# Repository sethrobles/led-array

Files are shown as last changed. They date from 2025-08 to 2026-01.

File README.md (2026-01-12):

# LED Array (32×32 STM32-Driven Matrix)

This repository contains the **hardware design and firmware** for a custom **32×32 LED matrix PCB** designed in **KiCad** and driven by an **STM32 microcontroller**.

The project was built both as a learning exercise in multi-layer PCB design and as a functional, firmware-controlled LED display.

🔗 **Project blog / design log:**
https://sethrobles.github.io/blogs/led-array/

---

## Project Overview

The LED array is implemented as a multiplexed matrix driven by shift registers and MOSFETs, with all timing and animation handled in firmware.

### Hardware Features

- **32×32 LED matrix** (1,032 LEDs total)
- **16× 74HC595 shift registers** for serial-to-parallel expansion
- **8× N-channel MOSFETs** for row/column current switching
- **STM32 microcontroller** for scanning, timing, and animation logic
- **On-board buck converter** for efficient 3.3 V regulation
- **4-layer PCB** designed and routed in KiCad
- **Hierarchical schematics** to support scalable layout and reuse

## Schematic Structure

The board uses an **on-board switching buck converter (TPS54331DR)** to step a ~5 V input down to 3.3V for the STM32 and logic circuitry.

The design uses a hierarchical schematic organization to keep both the schematic and PCB layout manageable:

- **LED Row**: 8 LEDs tied to a single shift-register output
- **LED Module**: One shift register driving 64 LEDs
- **LED Group**: Four LED modules grouped for layout and logic convenience

In total:
- **16 shift registers**
- **1,032 LEDs**

---

## Firmware

Firmware is written using **STM32CubeIDE** and is responsible for:

- High-speed LED scanning
- Register shifting and latch control
- Multiplex timing
- Multiple animation modes (spirals, perimeter effects, hearts, text, etc.)
- Minimizing ghosting and partial illumination

Programming and debugging are currently done using **ST-Link**. A future revision may include a USB bootloader to eliminate the need for programming headers.

Firmware lives alongside the hardware files but is kept logically separate. It is divided into 3 .c files: main, led_array, and frames. Main is actually uploaded to the board, led_array includes the basic logic for programming a frame, and frames contains specific frames for the board that build the animations.

---

## Repository Structure

- `Firmware/` – STM32 firmware source (CubeIDE project)
- KiCad project files – schematics, PCB layout, and libraries
- Backup and fabrication-related artifacts (not required for normal use)

---

## Status

The board has been fabricated, assembled, powered, and tested:

- Buck converter output verified (~20 mV ripple observed)
- STM32 successfully flashed and running on hardware
- LED scanning and animations functional

---

## Motivation & Inspiration

This project was inspired by:
- Phil’s Lab STM32 PCB design tutorials
- Guidance and feedback from friends with PCB design experience

The full design process, decisions, mistakes, and lessons learned are documented on the project blog.

📖 **Read the full build log:**
https://sethrobles.github.io/blogs/led-array/

*Summary Written with ChatGPT

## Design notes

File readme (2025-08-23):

# KiCad LED Array 🚧 (Work in Progress)

This project is a custom PCB built in **KiCad** that drives a 32×32 LED matrix using an **STM32 microcontroller**.

The design features:
- **8 NFETs** for row/column control
- **16 shift registers (74HC595)** for serial-to-parallel expansion
- A hierarchical schematic setup for scalability

### Inspiration
This project was inspired (and guided) by my friend [@floreacton](https://github.com/floreacton).

---

## Current Status
🚧 **In Progress**
This design is still being prototyped. Expect changes to both the schematic and PCB layout as I refine the design.

---

## Goals
- [ ] Finish schematic design and ERC checks
- [ ] Route PCB with proper 4-layer stackup
- [ ] Order prototype boards from JLCPCB
- [ ] Test LED scanning with STM32 firmware

---

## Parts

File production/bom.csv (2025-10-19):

Designator | Footprint | Quantity | Value | LCSC Part #
C1 | 1206 | 1 | 22uF | C12891
C10, C12, C13, C17, C18, C19, C20, C21, C22, C23, C24, C25, C26, C27, C28, C29, C3, C30, C31, C32, C7, C9 | 0402 | 22 | 100nF | C1525
C11, C33, C8 | 0402 | 3 | 10pF | C32949
C14 | 0603 | 1 | 10nF | C57112
C15, C16 | 0603 | 2 | 1uF | C15849
C2 | 0603 | 1 | 8n2F | C1322360
C4 | 0402 | 1 | 1nF | C1523
C5 | 1206 | 1 | 100uF | C15008
C6 | 1206 | 1 | 10uF | C13585
D1 | 0805 | 1 | GREEN_LIGHT | C2297
D10, D100, D1000, D1001, D1002, D1003, D1004, D1005, D1006, D1007, D1008, D1009, D101, D1010, D1011, D1012, D1013, D1014, D1015, D1016, D1017, D1018, D1019, D102, D1020, D1021, D1022, D1023, D1024, D1025, D103, D104, D105, D106, D107, D108, D109, D11, D110, D111, D112, D113, D114, D115, D116, D117, D118, D119, D12, D120, D121, D122, D123, D124, D125, D126, D127, D128, D129, D13, D130, D131, D132, D133, D134, D135, D136, D137, D138, D139, D14, D140, D141, D142, D143, D144, D145, D146, D147, D148, D149, D15, D150, D151, D152, D153, D154, D155, D156, D157, D158, D159, D16, D160, D161, D162, D163, D164, D165, D166, D167, D168, D169, D17, D170, D171, D172, D173, D174, D175, D176, D177, D178, D179, D18, D180, D181, D182, D183, D184, D185, D186, D187, D188, D189, D19, D190, D191, D192, D193, D194, D195, D196, D197, D198, D199, D2, D20, D200, D201, D202, D203, D204, D205, D206, D207, D208, D209, D21, D210, D211, D212, D213, D214, D215, D216, D217, D218, D219, D22, D220, D221, D222, D223, D224, D225, D226, D227, D228, D229, D23, D230, D231, D232, D233, D234, D235, D236, D237, D238, D239, D24, D240, D241, D242, D243, D244, D245, D246, D247, D248, D249, D25, D250, D251, D252, D253, D254, D255, D256 | 0603 | 200 | RED | C2286
D1026 | D_SMA | 1 | D_Schottky | C14996
D257, D258, D259, D26, D260, D261, D262, D263, D264, D265, D266, D267, D268, D269, D27, D270, D271, D272, D273, D274, D275, D276, D277, D278, D279, D28, D280, D281, D282, D283, D284, D285, D286, D287, D288, D289, D29, D290, D291, D292, D293, D294, D295, D296, D297, D298, D299, D3, D30, D300, D301, D302, D303, D304, D305, D306, D307, D308, D309, D31, D310, D311, D312, D313, D314, D315, D316, D317, D318, D319, D32, D320, D321, D322, D323, D324, D325, D326, D327, D328, D329, D33, D330, D331, D332, D333, D334, D335, D336, D337, D338, D339, D34, D340, D341, D342, D343, D344, D345, D346, D347, D348, D349, D35, D350, D351, D352, D353, D354, D355, D356, D357, D358, D359, D36, D360, D361, D362, D363, D364, D365, D366, D367, D368, D369, D37, D370, D371, D372, D373, D374, D375, D376, D377, D378, D379, D38, D380, D381, D382, D383, D384, D385, D386, D387, D388, D389, D39, D390, D391, D392, D393, D394, D395, D396, D397, D398, D399, D4, D40, D400, D401, D402, D403, D404, D405, D406, D407, D408, D409, D41, D410, D411, D412, D413, D414, D415, D416, D417, D418, D419, D42, D420, D421, D422, D423, D424, D425, D426, D427, D428, D429, D43, D430, D431, D432, D433, D434, D435, D436 | 0603 | 200 | RED | C2286
D437, D438, D439, D44, D440, D441, D442, D443, D444, D445, D446, D447, D448, D449, D45, D450, D451, D452, D453, D454, D455, D456, D457, D458, D459, D46, D460, D461, D462, D463, D464, D465, D466, D467, D468, D469, D47, D470, D471, D472, D473, D474, D475, D476, D477, D478, D479, D48, D480, D481, D482, D483, D484, D485, D486, D487, D488, D489, D49, D490, D491, D492, D493, D494, D495, D496, D497, D498, D499, D5, D50, D500, D501, D502, D503, D504, D505, D506, D507, D508, D509, D51, D510, D511, D512, D513, D514, D515, D516, D517, D518, D519, D52, D520, D521, D522, D523, D524, D525, D526, D527, D528, D529, D53, D530, D531, D532, D533, D534, D535, D536, D537, D538, D539, D54, D540, D541, D542, D543, D544, D545, D546, D547, D548, D549, D55, D550, D551, D552, D553, D554, D555, D556, D557, D558, D559, D56, D560, D561, D562, D563, D564, D565, D566, D567, D568, D569, D57, D570, D571, D572, D573, D574, D575, D576, D577, D578, D579, D58, D580, D581, D582, D583, D584, D585, D586, D587, D588, D589, D59, D590, D591, D592, D593, D594, D595, D596, D597, D598, D599, D6, D60, D600, D601, D602, D603, D604, D605, D606, D607, D608, D609, D61, D610, D611, D612, D613, D614, D615, D616 | 0603 | 200 | RED | C2286
D617, D618, D619, D62, D620, D621, D622, D623, D624, D625, D626, D627, D628, D629, D63, D630, D631, D632, D633, D634, D635, D636, D637, D638, D639, D64, D640, D641, D642, D643, D644, D645, D646, D647, D648, D649, D65, D650, D651, D652, D653, D654, D655, D656, D657, D658, D659, D66, D660, D661, D662, D663, D664, D665, D666, D667, D668, D669, D67, D670, D671, D672, D673, D674, D675, D676, D677, D678, D679, D68, D680, D681, D682, D683, D684, D685, D686, D687, D688, D689, D69, D690, D691, D692, D693, D694, D695, D696, D697, D698, D699, D7, D70, D700, D701, D702, D703, D704, D705, D706, D707, D708, D709, D71, D710, D711, D712, D713, D714, D715, D716, D717, D718, D719, D72, D720, D721, D722, D723, D724, D725, D726, D727, D728, D729, D73, D730, D731, D732, D733, D734, D735, D736, D737, D738, D739, D74, D740, D741, D742, D743, D744, D745, D746, D747, D748, D749, D75, D750, D751, D752, D753, D754, D755, D756, D757, D758, D759, D76, D760, D761, D762, D763, D764, D765, D766, D767, D768, D769, D77, D770, D771, D772, D773, D774, D775, D776, D777, D778, D779, D78, D780, D781, D782, D783, D784, D785, D786, D787, D788, D789, D79, D790, D791, D792, D793, D794, D795, D796, D797 | 0603 | 200 | RED | C2286
D798, D799, D8, D80, D800, D801, D802, D803, D804, D805, D806, D807, D808, D809, D81, D810, D811, D812, D813, D814, D815, D816, D817, D818, D819, D82, D820, D821, D822, D823, D824, D825, D826, D827, D828, D829, D83, D830, D831, D832, D833, D834, D835, D836, D837, D838, D839, D84, D840, D841, D842, D843, D844, D845, D846, D847, D848, D849, D85, D850, D851, D852, D853, D854, D855, D856, D857, D858, D859, D86, D860, D861, D862, D863, D864, D865, D866, D867, D868, D869, D87, D870, D871, D872, D873, D874, D875, D876, D877, D878, D879, D88, D880, D881, D882, D883, D884, D885, D886, D887, D888, D889, D89, D890, D891, D892, D893, D894, D895, D896, D897, D898, D899, D9, D90, D900, D901, D902, D903, D904, D905, D906, D907, D908, D909, D91, D910, D911, D912, D913, D914, D915, D916, D917, D918, D919, D92, D920, D921, D922, D923, D924, D925, D926, D927, D928, D929, D93, D930, D931, D932, D933, D934, D935, D936, D937, D938, D939, D94, D940, D941, D942, D943, D944, D945, D946, D947, D948, D949, D95, D950, D951, D952, D953, D954, D955, D956, D957, D958, D959, D96, D960, D961, D962, D963, D964, D965, D966, D967, D968, D969, D97, D970, D971, D972, D973, D974, D975, D976, D977 | 0603 | 200 | RED | C2286
D978, D979, D98, D980, D981, D982, D983, D984, D985, D986, D987, D988, D989, D99, D990, D991, D992, D993, D994, D995, D996, D997, D998, D999 | 0603 | 24 | RED | C2286
FB1 | 0603 | 1 | 120FB | C14709
J1 | PinHeader_1x04_P2.54mm_Vertical | 1 | Conn_01x04_Pin | C5116483
J2 | USB_Micro-B_Molex-105017-0001 | 1 | USB_B_Micro | C136000
L1 | L_Bourns-SRN8040_8x8.15mm | 1 | 3.6uH | C6496151
Q1, Q2, Q3, Q4, Q5, Q6, Q7, Q8 | SOT-23 | 8 | Q_NMOS_GDS | C8545
R1, R4 | 0805 | 2 | 10k | C17414
R10, R100, R101, R102, R103, R104, R105, R106, R107, R108, R109, R11, R110, R111, R112, R113, R114, R115, R116, R117, R118, R119, R12, R120, R121, R122, R123, R124, R125, R126, R127, R128, R129, R13, R130, R131, R132, R133, R134, R14, R15, R16, R17, R18, R19, R20, R21, R22, R23, R24, R25, R26, R27, R28, R29, R30, R31, R32, R33, R34, R35, R36, R37, R38, R39, R40, R41, R42, R43, R44, R45, R46, R47, R48, R49, R50, R51, R52, R53, R54, R55, R56, R57, R58, R59, R60, R61, R62, R63, R64, R65, R66, R67, R68, R69, R7, R70, R71, R72, R73, R74, R75, R76, R77, R78, R79, R8, R80, R81, R82, R83, R84, R85, R86, R87, R88, R89, R9, R90, R91, R92, R93, R94, R95, R96, R97, R98, R99 | 0402 | 128 | 200 | C25087
R135 | 0402 | 1 | 33k | C25779
R136 | 0402 | 1 | 3.3k | C25890
R2 | 0402 | 1 | 2k | C4109
R3 | 0603 | 1 | 1k2 | C22765
R5 | 0402 | 1 | 470 | C25117
R6 | 0603 | 1 | 1k5 | C22843
U1 | SOIC-8_3.9x4.9mm_P1.27mm | 1 | TPS54331DR | C9865
U10, U11, U12, U13, U14, U15, U16, U17, U18, U3, U4, U5, U6, U7, U8, U9 | SOIC-16_3.9x9.9mm_P1.27mm | 16 | 74HC595 | C5947
U2 | LQFP-48_7x7mm_P0.5mm | 1 | STM32F103C8T6 | C8734
Y1 | Crystal_SMD_3225-4Pin_3.2x2.5mm | 1 | 16MHz | C9002

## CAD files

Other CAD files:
qr-code/seth_qr.dxf

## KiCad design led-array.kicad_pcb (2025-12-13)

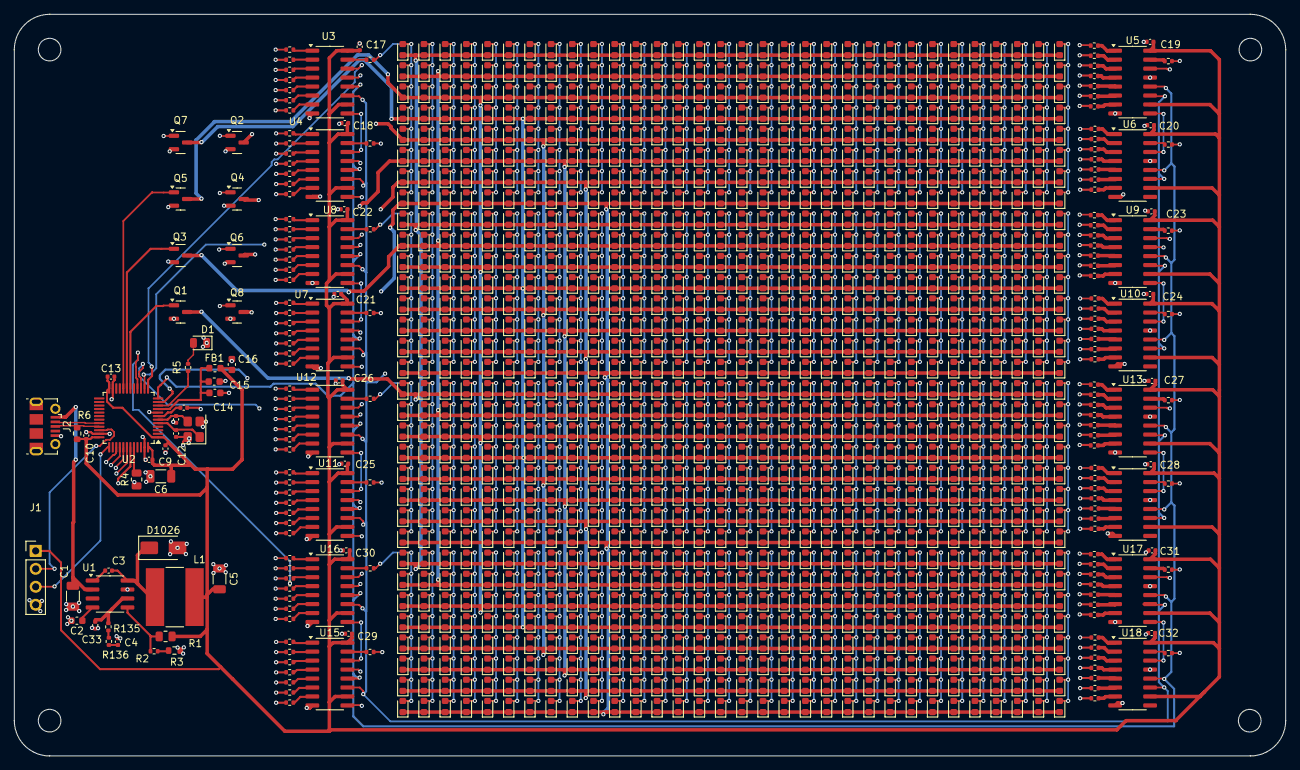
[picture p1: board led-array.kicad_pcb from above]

Board: 4 copper layers, 180.0 x 105.0 mm, 1230 parts (0 on the bottom side), 312 nets.

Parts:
C1: 22uF; C_1206_3216Metric
C2: 8n2F; C_0603_1608Metric
C3, C7, C9, C10, C12, C13, C17, C18, C19, C20, C21, C22, C23, C24, C25, C26, C27, C28, C29, C30, C31, C32: 100nF; C_0402_1005Metric
C4: 1nF; C_0402_1005Metric
C5: 100uF; C_1206_3216Metric
C6: 10uF; C_1206_3216Metric
C8, C11, C33: 10pF; C_0402_1005Metric
C14: 10nF; C_0603_1608Metric
C15, C16: 1uF; C_0603_1608Metric
D1: GREEN_LIGHT; LED_0805_2012Metric
D2, D3, D4, D5, D6, D7, D8, D9, D10, D11, D12, D13, D14, D15, D16, D17, D18, D19, D20, D21, D22, D23, D24, D25, D26, D27, D28, D29, D30, D31, D32, D33, D34, D35, D36, D37, D38, D39, D40, D41, D42, D43, D44, D45, D46, D47, D48, D49, D50, D51, D52, D53, D54, D55, D56, D57, D58, D59, D60, D61, D62, D63, D64, D65, D66, D67, D68, D69, D70, D71, D72, D73, D74, D75, D76, D77, D78, D79, D80, D81, D82, D83, D84, D85, D86, D87, D88, D89, D90, D91, D92, D93, D94, D95, D96, D97, D98, D99, D100, D101, D102, D103, D104, D105, D106, D107, D108, D109, D110, D111, D112, D113, D114, D115, D116, D117, D118, D119, D120, D121, D122, D123, D124, D125, D126, D127, D128, D129, D130, D131, D132, D133, D134, D135, D136, D137, D138, D139, D140, D141, D142, D143, D144, D145, D146, D147, D148, D149, D150, D151, D152, D153, D154, D155, D156, D157, D158, D159, D160, D161, D162, D163, D164, D165, D166, D167, D168, D169, D170, D171, D172, D173, D174, D175, D176, D177, D178, D179, D180, D181, D182, D183, D184, D185, D186, D187, D188, D189, D190, D191, D192, D193, D194, D195, D196, D197, D198, D199, D200, D201, D202, D203, D204, D205, D206, D207, D208, D209, D210, D211, D212, D213, D214, D215, D216, D217, D218, D219, D220, D221, D222, D223, D224, D225, D226, D227, D228, D229, D230, D231, D232, D233, D234, D235, D236, D237, D238, D239, D240, D241, D242, D243, D244, D245, D246, D247, D248, D249, D250, D251, D252, D253, D254, D255, D256, D257, D258, D259, D260, D261, D262, D263, D264, D265, D266, D267, D268, D269, D270, D271, D272, D273, D274, D275, D276, D277, D278, D279, D280, D281, D282, D283, D284, D285, D286, D287, D288, D289, D290, D291, D292, D293, D294, D295, D296, D297, D298, D299, D300, D301, D302, D303, D304, D305, D306, D307, D308, D309, D310, D311, D312, D313, D314, D315, D316, D317, D318, D319, D320, D321, D322, D323, D324, D325, D326, D327, D328, D329, D330, D331, D332, D333, D334, D335, D336, D337, D338, D339, D340, D341, D342, D343, D344, D345, D346, D347, D348, D349, D350, D351, D352, D353, D354, D355, D356, D357, D358, D359, D360, D361, D362, D363, D364, D365, D366, D367, D368, D369, D370, D371, D372, D373, D374, D375, D376, D377, D378, D379, D380, D381, D382, D383, D384, D385, D386, D387, D388, D389, D390, D391, D392, D393, D394, D395, D396, D397, D398, D399, D400, D401, D402, D403, D404, D405, D406, D407, D408, D409, D410, D411, D412, D413, D414, D415, D416, D417, D418, D419, D420, D421, D422, D423, D424, D425, D426, D427, D428, D429, D430, D431, D432, D433, D434, D435, D436, D437, D438, D439, D440, D441, D442, D443, D444, D445, D446, D447, D448, D449, D450, D451, D452, D453, D454, D455, D456, D457, D458, D459, D460, D461, D462, D463, D464, D465, D466, D467, D468, D469, D470, D471, D472, D473, D474, D475, D476, D477, D478, D479, D480, D481, D482, D483, D484, D485, D486, D487, D488, D489, D490, D491, D492, D493, D494, D495, D496, D497, D498, D499, D500, D501, D502, D503, D504, D505, D506, D507, D508, D509, D510, D511, D512, D513, D514, D515, D516, D517, D518, D519, D520, D521, D522, D523, D524, D525, D526, D527, D528, D529, D530, D531, D532, D533, D534, D535, D536, D537, D538, D539, D540, D541, D542, D543, D544, D545, D546, D547, D548, D549, D550, D551, D552, D553, D554, D555, D556, D557, D558, D559, D560, D561, D562, D563, D564, D565, D566, D567, D568, D569, D570, D571, D572, D573, D574, D575, D576, D577, D578, D579, D580, D581, D582, D583, D584, D585, D586, D587, D588, D589, D590, D591, D592, D593, D594, D595, D596, D597, D598, D599, D600, D601, D602, D603, D604, D605, D606, D607, D608, D609, D610, D611, D612, D613, D614, D615, D616, D617, D618, D619, D620, D621, D622, D623, D624, D625, D626, D627, D628, D629, D630, D631, D632, D633, D634, D635, D636, D637, D638, D639, D640, D641, D642, D643, D644, D645, D646, D647, D648, D649, D650, D651, D652, D653, D654, D655, D656, D657, D658, D659, D660, D661, D662, D663, D664, D665, D666, D667, D668, D669, D670, D671, D672, D673, D674, D675, D676, D677, D678, D679, D680, D681, D682, D683, D684, D685, D686, D687, D688, D689, D690, D691, D692, D693, D694, D695, D696, D697, D698, D699, D700, D701, D702, D703, D704, D705, D706, D707, D708, D709, D710, D711, D712, D713, D714, D715, D716, D717, D718, D719, D720, D721, D722, D723, D724, D725, D726, D727, D728, D729, D730, D731, D732, D733, D734, D735, D736, D737, D738, D739, D740, D741, D742, D743, D744, D745, D746, D747, D748, D749, D750, D751, D752, D753, D754, D755, D756, D757, D758, D759, D760, D761, D762, D763, D764, D765, D766, D767, D768, D769, D770, D771, D772, D773, D774, D775, D776, D777, D778, D779, D780, D781, D782, D783, D784, D785, D786, D787, D788, D789, D790, D791, D792, D793, D794, D795, D796, D797, D798, D799, D800, D801, D802, D803, D804, D805, D806, D807, D808, D809, D810, D811, D812, D813, D814, D815, D816, D817, D818, D819, D820, D821, D822, D823, D824, D825, D826, D827, D828, D829, D830, D831, D832, D833, D834, D835, D836, D837, D838, D839, D840, D841, D842, D843, D844, D845, D846, D847, D848, D849, D850, D851, D852, D853, D854, D855, D856, D857, D858, D859, D860, D861, D862, D863, D864, D865, D866, D867, D868, D869, D870, D871, D872, D873, D874, D875, D876, D877, D878, D879, D880, D881, D882, D883, D884, D885, D886, D887, D888, D889, D890, D891, D892, D893, D894, D895, D896, D897, D898, D899, D900, D901, D902, D903, D904, D905, D906, D907, D908, D909, D910, D911, D912, D913, D914, D915, D916, D917, D918, D919, D920, D921, D922, D923, D924, D925, D926, D927, D928, D929, D930, D931, D932, D933, D934, D935, D936, D937, D938, D939, D940, D941, D942, D943, D944, D945, D946, D947, D948, D949, D950, D951, D952, D953, D954, D955, D956, D957, D958, D959, D960, D961, D962, D963, D964, D965, D966, D967, D968, D969, D970, D971, D972, D973, D974, D975, D976, D977, D978, D979, D980, D981, D982, D983, D984, D985, D986, D987, D988, D989, D990, D991, D992, D993, D994, D995, D996, D997, D998, D999, D1000, D1001, D1002, D1003, D1004, D1005, D1006, D1007, D1008, D1009, D1010, D1011, D1012, D1013, D1014, D1015, D1016, D1017, D1018, D1019, D1020, D1021, D1022, D1023, D1024, D1025: RED; LED_0603_1608Metric
D1026: D_Schottky; D_SMA
FB1: 120FB; L_0603_1608Metric
H1, H2, H3, H4: MountingHole; MountingHole_3.2mm_M3
J1: Conn_01x04_Pin; PinHeader_1x04_P2.54mm_Vertical
J2: USB_B_Micro; USB_Micro-B_Molex-105017-0001
L1: 3.6uH; L_Bourns-SRN8040_8x8.15mm
Q1, Q2, Q3, Q4, Q5, Q6, Q7, Q8: Q_NMOS_GDS; SOT-23
R1, R4: 10k; R_0805_2012Metric
R2: 2k; R_0402_1005Metric
R3: 1k2; R_0603_1608Metric
R5: 470; R_0402_1005Metric
R6: 1k5; R_0603_1608Metric
R7, R8, R9, R10, R11, R12, R13, R14, R15, R16, R17, R18, R19, R20, R21, R22, R23, R24, R25, R26, R27, R28, R29, R30, R31, R32, R33, R34, R35, R36, R37, R38, R39, R40, R41, R42, R43, R44, R45, R46, R47, R48, R49, R50, R51, R52, R53, R54, R55, R56, R57, R58, R59, R60, R61, R62, R63, R64, R65, R66, R67, R68, R69, R70, R71, R72, R73, R74, R75, R76, R77, R78, R79, R80, R81, R82, R83, R84, R85, R86, R87, R88, R89, R90, R91, R92, R93, R94, R95, R96, R97, R98, R99, R100, R101, R102, R103, R104, R105, R106, R107, R108, R109, R110, R111, R112, R113, R114, R115, R116, R117, R118, R119, R120, R121, R122, R123, R124, R125, R126, R127, R128, R129, R130, R131, R132, R133, R134: 200; R_0402_1005Metric
R135: 33k; R_0402_1005Metric
R136: 3.3k; R_0402_1005Metric
U1: TPS54331DR; SOIC-8_3.9x4.9mm_P1.27mm
U2: STM32F103C8T6; LQFP-48_7x7mm_P0.5mm
U3, U4, U5, U6, U7, U8, U9, U10, U11, U12, U13, U14, U15, U16, U17, U18: 74HC595; SOIC-16_3.9x9.9mm_P1.27mm
Y1: 16MHz; Crystal_SMD_3225-4Pin_3.2x2.5mm

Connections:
+3.3V: C5.1, C6.1, C9.1, C10.1, C12.1, C13.1, C16.1, C17.1, C18.1, C19.1, C20.1, C21.1, C22.1, C23.1, C24.1, C25.1, C26.1, C27.1, C28.1, C29.1, C30.1, C31.1, C32.1, FB1.2, J1.1, L1.2, R1.1, R6.2, U2.1 (VBAT), U2.24 (VDD), U2.36 (VDD), U2.48 (VDD), U3.10 (~SRCLR), U3.16 (VCC), U4.10 (~SRCLR), U4.16 (VCC), U5.10 (~SRCLR), U5.16 (VCC), U6.10 (~SRCLR), U6.16 (VCC), U7.10 (~SRCLR), U7.16 (VCC), U8.10 (~SRCLR), U8.16 (VCC), U9.10 (~SRCLR), U9.16 (VCC), U10.10 (~SRCLR), U10.16 (VCC), U11.10 (~SRCLR), U11.16 (VCC), U12.10 (~SRCLR), U12.16 (VCC), U13.10 (~SRCLR), U13.16 (VCC), U14.10 (~SRCLR), U14.16 (VCC), U15.10 (~SRCLR), U15.16 (VCC), U16.10 (~SRCLR), U16.16 (VCC), U17.10 (~SRCLR), U17.16 (VCC), U18.10 (~SRCLR), U18.16 (VCC)
+3.3VA: C14.1, C15.1, FB1.1, U2.9 (VDDA)
/BOOT0: R4.2, U2.44 (BOOT0)
/Cboot: C3.2, U1.1 (BOOT)
/HSE_IN: C8.2, U2.5 (PD0), Y1.1
/HSE_OUT: C11.2, U2.6 (PD1), Y1.3
/LED Group 0/Led Module 1/A0: D2.2 (A), D10.2 (A), D18.2 (A), D26.2 (A), D34.2 (A), D42.2 (A), D50.2 (A), D58.2 (A), R7.2
/LED Group 0/Led Module 1/A1: D3.2 (A), D11.2 (A), D19.2 (A), D27.2 (A), D35.2 (A), D43.2 (A), D51.2 (A), D59.2 (A), R8.2
/LED Group 0/Led Module 1/A2: D4.2 (A), D12.2 (A), D20.2 (A), D28.2 (A), D36.2 (A), D44.2 (A), D52.2 (A), D60.2 (A), R9.2
/LED Group 0/Led Module 1/A3: D5.2 (A), D13.2 (A), D21.2 (A), D29.2 (A), D37.2 (A), D45.2 (A), D53.2 (A), D61.2 (A), R10.2
/LED Group 0/Led Module 1/A4: D6.2 (A), D14.2 (A), D22.2 (A), D30.2 (A), D38.2 (A), D46.2 (A), D54.2 (A), D62.2 (A), R11.2
/LED Group 0/Led Module 1/A5: D7.2 (A), D15.2 (A), D23.2 (A), D31.2 (A), D39.2 (A), D47.2 (A), D55.2 (A), D63.2 (A), R12.2
/LED Group 0/Led Module 1/A6: D8.2 (A), D16.2 (A), D24.2 (A), D32.2 (A), D40.2 (A), D48.2 (A), D56.2 (A), D64.2 (A), R13.2
/LED Group 0/Led Module 1/A7: D9.2 (A), D17.2 (A), D25.2 (A), D33.2 (A), D41.2 (A), D49.2 (A), D57.2 (A), D65.2 (A), R14.2
/LED Group 0/Led Module 1/OUT: U3.9 (QH'), U4.14 (SER)
/LED Group 0/Led Module 2/A0: D66.2 (A), D74.2 (A), D82.2 (A), D90.2 (A), D98.2 (A), D106.2 (A), D114.2 (A), D122.2 (A), R15.2
/LED Group 0/Led Module 2/A1: D67.2 (A), D75.2 (A), D83.2 (A), D91.2 (A), D99.2 (A), D107.2 (A), D115.2 (A), D123.2 (A), R16.2
/LED Group 0/Led Module 2/A2: D68.2 (A), D76.2 (A), D84.2 (A), D92.2 (A), D100.2 (A), D108.2 (A), D116.2 (A), D124.2 (A), R17.2
/LED Group 0/Led Module 2/A3: D69.2 (A), D77.2 (A), D85.2 (A), D93.2 (A), D101.2 (A), D109.2 (A), D117.2 (A), D125.2 (A), R18.2
/LED Group 0/Led Module 2/A4: D70.2 (A), D78.2 (A), D86.2 (A), D94.2 (A), D102.2 (A), D110.2 (A), D118.2 (A), D126.2 (A), R19.2
/LED Group 0/Led Module 2/A5: D71.2 (A), D79.2 (A), D87.2 (A), D95.2 (A), D103.2 (A), D111.2 (A), D119.2 (A), D127.2 (A), R20.2
/LED Group 0/Led Module 2/A6: D72.2 (A), D80.2 (A), D88.2 (A), D96.2 (A), D104.2 (A), D112.2 (A), D120.2 (A), D128.2 (A), R21.2
/LED Group 0/Led Module 2/A7: D73.2 (A), D81.2 (A), D89.2 (A), D97.2 (A), D105.2 (A), D113.2 (A), D121.2 (A), D129.2 (A), R22.2
/LED Group 0/Led Module 2/OUT: U4.9 (QH'), U5.14 (SER)
/LED Group 0/Led Module 3/A0: D130.2 (A), D138.2 (A), D146.2 (A), D154.2 (A), D162.2 (A), D170.2 (A), D218.2 (A), D226.2 (A), R23.2
/LED Group 0/Led Module 3/A1: D131.2 (A), D139.2 (A), D147.2 (A), D155.2 (A), D163.2 (A), D171.2 (A), D219.2 (A), D227.2 (A), R24.2
/LED Group 0/Led Module 3/A2: D132.2 (A), D140.2 (A), D148.2 (A), D156.2 (A), D164.2 (A), D172.2 (A), D220.2 (A), D228.2 (A), R25.2
/LED Group 0/Led Module 3/A3: D133.2 (A), D141.2 (A), D149.2 (A), D157.2 (A), D165.2 (A), D173.2 (A), D221.2 (A), D229.2 (A), R26.2
/LED Group 0/Led Module 3/A4: D134.2 (A), D142.2 (A), D150.2 (A), D158.2 (A), D166.2 (A), D174.2 (A), D222.2 (A), D230.2 (A), R27.2
/LED Group 0/Led Module 3/A5: D135.2 (A), D143.2 (A), D151.2 (A), D159.2 (A), D167.2 (A), D175.2 (A), D223.2 (A), D231.2 (A), R28.2
/LED Group 0/Led Module 3/A6: D136.2 (A), D144.2 (A), D152.2 (A), D160.2 (A), D168.2 (A), D176.2 (A), D224.2 (A), D232.2 (A), R29.2
/LED Group 0/Led Module 3/A7: D137.2 (A), D145.2 (A), D153.2 (A), D161.2 (A), D169.2 (A), D177.2 (A), D225.2 (A), D233.2 (A), R30.2
/LED Group 0/Led Module 3/OUT: U5.9 (QH'), U6.14 (SER)
/LED Group 0/Led Module 4/A0: D274.2 (A), D282.2 (A), D338.2 (A), D346.2 (A), D394.2 (A), D402.2 (A), D450.2 (A), D458.2 (A), R31.2
/LED Group 0/Led Module 4/A1: D275.2 (A), D283.2 (A), D339.2 (A), D347.2 (A), D395.2 (A), D403.2 (A), D451.2 (A), D459.2 (A), R32.2
/LED Group 0/Led Module 4/A2: D276.2 (A), D284.2 (A), D340.2 (A), D348.2 (A), D396.2 (A), D404.2 (A), D452.2 (A), D460.2 (A), R33.2
/LED Group 0/Led Module 4/A3: D277.2 (A), D285.2 (A), D341.2 (A), D349.2 (A), D397.2 (A), D405.2 (A), D453.2 (A), D461.2 (A), R34.2
/LED Group 0/Led Module 4/A4: D278.2 (A), D286.2 (A), D342.2 (A), D350.2 (A), D398.2 (A), D406.2 (A), D454.2 (A), D462.2 (A), R35.2
/LED Group 0/Led Module 4/A5: D279.2 (A), D287.2 (A), D343.2 (A), D351.2 (A), D399.2 (A), D407.2 (A), D455.2 (A), D463.2 (A), R36.2
/LED Group 0/Led Module 4/A6: D280.2 (A), D288.2 (A), D344.2 (A), D352.2 (A), D400.2 (A), D408.2 (A), D456.2 (A), D464.2 (A), R37.2
/LED Group 0/Led Module 4/A7: D281.2 (A), D289.2 (A), D345.2 (A), D353.2 (A), D401.2 (A), D409.2 (A), D457.2 (A), D465.2 (A), R38.2
/LED Group 1/Led Module 1/A0: D258.2 (A), D266.2 (A), D290.2 (A), D298.2 (A), D306.2 (A), D314.2 (A), D322.2 (A), D330.2 (A), R47.2
/LED Group 1/Led Module 1/A1: D259.2 (A), D267.2 (A), D291.2 (A), D299.2 (A), D307.2 (A), D315.2 (A), D323.2 (A), D331.2 (A), R48.2
/LED Group 1/Led Module 1/A2: D260.2 (A), D268.2 (A), D292.2 (A), D300.2 (A), D308.2 (A), D316.2 (A), D324.2 (A), D332.2 (A), R49.2
/LED Group 1/Led Module 1/A3: D261.2 (A), D269.2 (A), D293.2 (A), D301.2 (A), D309.2 (A), D317.2 (A), D325.2 (A), D333.2 (A), R50.2
/LED Group 1/Led Module 1/A4: D262.2 (A), D270.2 (A), D294.2 (A), D302.2 (A), D310.2 (A), D318.2 (A), D326.2 (A), D334.2 (A), R51.2
/LED Group 1/Led Module 1/A5: D263.2 (A), D271.2 (A), D295.2 (A), D303.2 (A), D311.2 (A), D319.2 (A), D327.2 (A), D335.2 (A), R52.2
/LED Group 1/Led Module 1/A6: D264.2 (A), D272.2 (A), D296.2 (A), D304.2 (A), D312.2 (A), D320.2 (A), D328.2 (A), D336.2 (A), R53.2
/LED Group 1/Led Module 1/A7: D265.2 (A), D273.2 (A), D297.2 (A), D305.2 (A), D313.2 (A), D321.2 (A), D329.2 (A), D337.2 (A), R54.2
/LED Group 1/Led Module 1/OUT: U7.14 (SER), U8.9 (QH')
/LED Group 1/Led Module 2/A0: D178.2 (A), D186.2 (A), D194.2 (A), D202.2 (A), D210.2 (A), D234.2 (A), D242.2 (A), D250.2 (A), R39.2
/LED Group 1/Led Module 2/A1: D179.2 (A), D187.2 (A), D195.2 (A), D203.2 (A), D211.2 (A), D235.2 (A), D243.2 (A), D251.2 (A), R40.2
/LED Group 1/Led Module 2/A2: D180.2 (A), D188.2 (A), D196.2 (A), D204.2 (A), D212.2 (A), D236.2 (A), D244.2 (A), D252.2 (A), R41.2
/LED Group 1/Led Module 2/A3: D181.2 (A), D189.2 (A), D197.2 (A), D205.2 (A), D213.2 (A), D237.2 (A), D245.2 (A), D253.2 (A), R42.2
/LED Group 1/Led Module 2/A4: D182.2 (A), D190.2 (A), D198.2 (A), D206.2 (A), D214.2 (A), D238.2 (A), D246.2 (A), D254.2 (A), R43.2
/LED Group 1/Led Module 2/A5: D183.2 (A), D191.2 (A), D199.2 (A), D207.2 (A), D215.2 (A), D239.2 (A), D247.2 (A), D255.2 (A), R44.2
/LED Group 1/Led Module 2/A6: D184.2 (A), D192.2 (A), D200.2 (A), D208.2 (A), D216.2 (A), D240.2 (A), D248.2 (A), D256.2 (A), R45.2
/LED Group 1/Led Module 2/A7: D185.2 (A), D193.2 (A), D201.2 (A), D209.2 (A), D217.2 (A), D241.2 (A), D249.2 (A), D257.2 (A), R46.2
/LED Group 1/Led Module 2/OUT: U7.9 (QH'), U9.14 (SER)
/LED Group 1/Led Module 3/A0: D354.2 (A), D362.2 (A), D370.2 (A), D378.2 (A), D386.2 (A), D410.2 (A), D418.2 (A), D426.2 (A), R55.2
/LED Group 1/Led Module 3/A1: D355.2 (A), D363.2 (A), D371.2 (A), D379.2 (A), D387.2 (A), D411.2 (A), D419.2 (A), D427.2 (A), R56.2
/LED Group 1/Led Module 3/A2: D356.2 (A), D364.2 (A), D372.2 (A), D380.2 (A), D388.2 (A), D412.2 (A), D420.2 (A), D428.2 (A), R57.2
/LED Group 1/Led Module 3/A3: D357.2 (A), D365.2 (A), D373.2 (A), D381.2 (A), D389.2 (A), D413.2 (A), D421.2 (A), D429.2 (A), R58.2
/LED Group 1/Led Module 3/A4: D358.2 (A), D366.2 (A), D374.2 (A), D382.2 (A), D390.2 (A), D414.2 (A), D422.2 (A), D430.2 (A), R59.2
/LED Group 1/Led Module 3/A5: D359.2 (A), D367.2 (A), D375.2 (A), D383.2 (A), D391.2 (A), D415.2 (A), D423.2 (A), D431.2 (A), R60.2
/LED Group 1/Led Module 3/A6: D360.2 (A), D368.2 (A), D376.2 (A), D384.2 (A), D392.2 (A), D416.2 (A), D424.2 (A), D432.2 (A), R61.2
/LED Group 1/Led Module 3/A7: D361.2 (A), D369.2 (A), D377.2 (A), D385.2 (A), D393.2 (A), D417.2 (A), D425.2 (A), D433.2 (A), R62.2
/LED Group 1/Led Module 3/OUT: U9.9 (QH'), U10.14 (SER)
/LED Group 1/Led Module 4/A0: D434.2 (A), D442.2 (A), D466.2 (A), D474.2 (A), D482.2 (A), D490.2 (A), D498.2 (A), D506.2 (A), R63.2
/LED Group 1/Led Module 4/A1: D435.2 (A), D443.2 (A), D467.2 (A), D475.2 (A), D483.2 (A), D491.2 (A), D499.2 (A), D507.2 (A), R64.2
/LED Group 1/Led Module 4/A2: D436.2 (A), D444.2 (A), D468.2 (A), D476.2 (A), D484.2 (A), D492.2 (A), D500.2 (A), D508.2 (A), R65.2
/LED Group 1/Led Module 4/A3: D437.2 (A), D445.2 (A), D469.2 (A), D477.2 (A), D485.2 (A), D493.2 (A), D501.2 (A), D509.2 (A), R66.2
/LED Group 1/Led Module 4/A4: D438.2 (A), D446.2 (A), D470.2 (A), D478.2 (A), D486.2 (A), D494.2 (A), D502.2 (A), D510.2 (A), R67.2
/LED Group 1/Led Module 4/A5: D439.2 (A), D447.2 (A), D471.2 (A), D479.2 (A), D487.2 (A), D495.2 (A), D503.2 (A), D511.2 (A), R68.2
/LED Group 1/Led Module 4/A6: D440.2 (A), D448.2 (A), D472.2 (A), D480.2 (A), D488.2 (A), D496.2 (A), D504.2 (A), D512.2 (A), R69.2
/LED Group 1/Led Module 4/A7: D441.2 (A), D449.2 (A), D473.2 (A), D481.2 (A), D489.2 (A), D497.2 (A), D505.2 (A), D513.2 (A), R70.2
/LED Group 2/Led Module 1/A0: D578.2 (A), D586.2 (A), D594.2 (A), D602.2 (A), D610.2 (A), D618.2 (A), D626.2 (A), D634.2 (A), R79.2
/LED Group 2/Led Module 1/A1: D579.2 (A), D587.2 (A), D595.2 (A), D603.2 (A), D611.2 (A), D619.2 (A), D627.2 (A), D635.2 (A), R80.2
/LED Group 2/Led Module 1/A2: D580.2 (A), D588.2 (A), D596.2 (A), D604.2 (A), D612.2 (A), D620.2 (A), D628.2 (A), D636.2 (A), R81.2
/LED Group 2/Led Module 1/A3: D581.2 (A), D589.2 (A), D597.2 (A), D605.2 (A), D613.2 (A), D621.2 (A), D629.2 (A), D637.2 (A), R82.2
/LED Group 2/Led Module 1/A4: D582.2 (A), D590.2 (A), D598.2 (A), D606.2 (A), D614.2 (A), D622.2 (A), D630.2 (A), D638.2 (A), R83.2
/LED Group 2/Led Module 1/A5: D583.2 (A), D591.2 (A), D599.2 (A), D607.2 (A), D615.2 (A), D623.2 (A), D631.2 (A), D639.2 (A), R84.2
/LED Group 2/Led Module 1/A6: D584.2 (A), D592.2 (A), D600.2 (A), D608.2 (A), D616.2 (A), D624.2 (A), D632.2 (A), D640.2 (A), R85.2
/LED Group 2/Led Module 1/A7: D585.2 (A), D593.2 (A), D601.2 (A), D609.2 (A), D617.2 (A), D625.2 (A), D633.2 (A), D641.2 (A), R86.2
/LED Group 2/Led Module 1/OUT: U11.14 (SER), U12.9 (QH')
/LED Group 2/Led Module 2/A0: D514.2 (A), D522.2 (A), D530.2 (A), D538.2 (A), D546.2 (A), D554.2 (A), D562.2 (A), D570.2 (A), R71.2
/LED Group 2/Led Module 2/A1: D515.2 (A), D523.2 (A), D531.2 (A), D539.2 (A), D547.2 (A), D555.2 (A), D563.2 (A), D571.2 (A), R72.2
/LED Group 2/Led Module 2/A2: D516.2 (A), D524.2 (A), D532.2 (A), D540.2 (A), D548.2 (A), D556.2 (A), D564.2 (A), D572.2 (A), R73.2
/LED Group 2/Led Module 2/A3: D517.2 (A), D525.2 (A), D533.2 (A), D541.2 (A), D549.2 (A), D557.2 (A), D565.2 (A), D573.2 (A), R74.2
/LED Group 2/Led Module 2/A4: D518.2 (A), D526.2 (A), D534.2 (A), D542.2 (A), D550.2 (A), D558.2 (A), D566.2 (A), D574.2 (A), R75.2
/LED Group 2/Led Module 2/A5: D519.2 (A), D527.2 (A), D535.2 (A), D543.2 (A), D551.2 (A), D559.2 (A), D567.2 (A), D575.2 (A), R76.2
/LED Group 2/Led Module 2/A6: D520.2 (A), D528.2 (A), D536.2 (A), D544.2 (A), D552.2 (A), D560.2 (A), D568.2 (A), D576.2 (A), R77.2
/LED Group 2/Led Module 2/A7: D521.2 (A), D529.2 (A), D537.2 (A), D545.2 (A), D553.2 (A), D561.2 (A), D569.2 (A), D577.2 (A), R78.2
/LED Group 2/Led Module 2/OUT: U11.9 (QH'), U13.14 (SER)
/LED Group 2/Led Module 3/A0: D642.2 (A), D650.2 (A), D658.2 (A), D666.2 (A), D674.2 (A), D682.2 (A), D690.2 (A), D698.2 (A), R87.2
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

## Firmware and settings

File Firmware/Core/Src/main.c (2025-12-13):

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
/* Includes ------------------------------------------------------------------*/
#include "main.h"
#include "led_array.h"
#include "frames.h"
/* USER CODE BEGIN Includes */
#include <stdbool.h>
/* USER CODE END Includes */

PCD_HandleTypeDef hpcd_USB_FS;


void SystemClock_Config(void);
static void MX_GPIO_Init(void);
static void MX_USB_PCD_Init(void);
/* USER CODE BEGIN PFP */
bool myFunction(int value);
/* USER CODE END PFP */

/**
  * @brief  The application entry point.
  * @retval int
  */
int main(void)
{

  /* MCU Configuration--------------------------------------------------------*/

  /* Reset of all peripherals, Initializes the Flash interface and the Systick. */
  HAL_Init();

  /* Configure the system clock */
  SystemClock_Config();

  /* Initialize all configured peripherals */
  MX_GPIO_Init();
  MX_USB_PCD_Init();
  /* USER CODE BEGIN 3 */



  while (1)
  {

//  writeFrame(blank32x32);

  HAL_Delay(1000);

  repeatFrame(a_s_heartFrame, 60);
  HAL_Delay(2000);
//  animateDiagonalDot(1);
  animateCornersAroundEdges(1);
  animateSpriteBubbles(SPRITE_HEART, 200, 40);
//  animateSpriteBubbles(SPRITE_SNOWFLAKE, 200, 40);
  animateFireworks(5, 400);  // 5 fireworks, tweak 400 for speed

//  animateBorderDot(1);
  repeatFrame_20(aFrame);
  repeatFrame_20(vFrame);
  repeatFrame_20(aFrame);

  HAL_Delay(100);

  repeatFrame_20(iFrame);
  repeatFrame_20(heartFrame);
  repeatFrame_20(yFrame);
  repeatFrame_20(oFrame);
  repeatFrame_20(uFrame);





  HAL_Delay(100);




//writeFrame(largerleftdiagonal_32x32);
//writeFrame(bottomRightDiagonal8_32x32);
//writeFrame(diagonal32x32);
//
//HAL_Delay(20);
//writeFrame(partialDiagonal32x32);
//HAL_Delay(100);
//writeFrame(blank32x32);
//HAL_Delay(20);
//
//writeFrame(border32x32);
//HAL_Delay(20);
//
//writeFrame(corners32x32);
//HAL_Delay(20);
//
//writeFrame(leftColumn32x32);
//HAL_Delay(20);
//
//writeFrame(fourRandomColumns32x32);



//  HAL_Delay(100);  // pause between full-frame updates
//writeFrame(centerColumn32x32);


    /* USER CODE END WHILE */

  }
  /* USER CODE END 3 */
}

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


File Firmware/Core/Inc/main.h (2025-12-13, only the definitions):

#define Green_LED_Pin GPIO_PIN_0
#define Green_LED_GPIO_Port GPIOA
#define SRCLK_Pin GPIO_PIN_1
#define SRCLK_GPIO_Port GPIOA
#define RCLK_Pin GPIO_PIN_2
#define RCLK_GPIO_Port GPIOA
#define SER0_Pin GPIO_PIN_3
#define SER0_GPIO_Port GPIOA
#define SER1_Pin GPIO_PIN_4
#define SER1_GPIO_Port GPIOA
#define SER2_Pin GPIO_PIN_5
#define SER2_GPIO_Port GPIOA
#define SER3_Pin GPIO_PIN_6
#define SER3_GPIO_Port GPIOA
#define M0_Pin GPIO_PIN_0
#define M0_GPIO_Port GPIOB
#define M1_Pin GPIO_PIN_1
#define M1_GPIO_Port GPIOB
#define M2_Pin GPIO_PIN_2
#define M2_GPIO_Port GPIOB
#define M3_Pin GPIO_PIN_3
#define M3_GPIO_Port GPIOB
#define M4_Pin GPIO_PIN_4
#define M4_GPIO_Port GPIOB
#define M5_Pin GPIO_PIN_5
#define M5_GPIO_Port GPIOB
#define M6_Pin GPIO_PIN_6
#define M6_GPIO_Port GPIOB
#define M7_Pin GPIO_PIN_7
#define M7_GPIO_Port GPIOB

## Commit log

2025-09-05 LED updates with some layout
    [led-array.kicad_sch, led_group.kicad_sch, led_module_1.kicad_sch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]
2025-09-16 LEDS wired
    [led-array.kicad_pcb, led-array.kicad_sch, led_group.kicad_sch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]
2025-09-17 Set up RCLK and SRCLK lines
    [led-array.kicad_sch, led-array_backup.kicad_pcb]
2025-09-18 Main power and signals wired
    [led-array.kicad_pcb, led-array.kicad_sch]
2025-09-20 update for miguel
    [led-array.kicad_pcb]
2025-09-26 Relabeled MOSFETs
    [led-array.kicad_pcb, led-array.kicad_sch, led_module_1.kicad_sch]
2025-09-29 Everything wired up
    [led-array.kicad_pcb, led-array.kicad_sch]
2025-09-29 Actually hopefully final
    [led-array.kicad_pcb]
2025-10-01 PCB laid out
    [led-array.kicad_pcb, led_row.kicad_sch]
2025-10-13 Updated schematic, still likely need to modify the buck converter
    [led-array-B_Cu.gbl, led-array-B_Mask.gbs, led-array-B_Paste.gbp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]
2025-10-18 Modified buck converter in schematic and pcb and got rid of old fabrication files
    [led-array-B_Cu.gbl, led-array-B_Mask.gbs, led-array-B_Paste.gbp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]
2025-10-18 Made more edits
    [MP1584EN-LF-Z.step, MP2338GTL-Z.step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]
2025-10-19 Updated usb-micro, have filled in all LCSC fields
    [bom.csv, designators.csv, led-array.kicad_pcb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]
2025-10-19 Modified pins to match JLCPCB layout
    [led-array.kicad_pcb, positions.csv]
2025-12-13 Added firwmare code
    [designators.csv, led-array.kicad_pcb, positions.csv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]

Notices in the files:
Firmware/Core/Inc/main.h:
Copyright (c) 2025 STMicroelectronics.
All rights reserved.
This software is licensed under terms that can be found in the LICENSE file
